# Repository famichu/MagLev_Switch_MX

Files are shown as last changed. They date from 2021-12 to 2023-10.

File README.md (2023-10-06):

# MagLev Switch MX

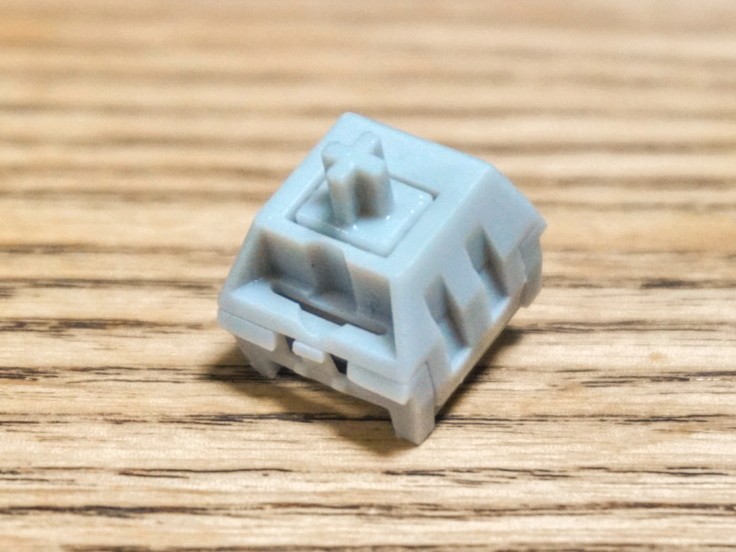
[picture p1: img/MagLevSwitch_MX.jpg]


## Summary
These 3D printable switches have linear output hall effect sensors with magnetic levitation switches. The shape of this swich is compatable with the Cherry MX switch.

## Features
- Magnetic levitation axis
- Non-contact switch
- Linear output(adjustable actuation depth)
- Able to make with only 2 magnets and a hall sensor.
- Compatible shape with Cherry MX switch

## Structure
Most MagLev switches don't use hall effect sensors. I think this is because the magnetism is too strong or the distance from the magnet is too close to for the sensor to detect. Therefore I implemented with new method that by sandwiching the hall effect sensor between two magnets instead of using springs.

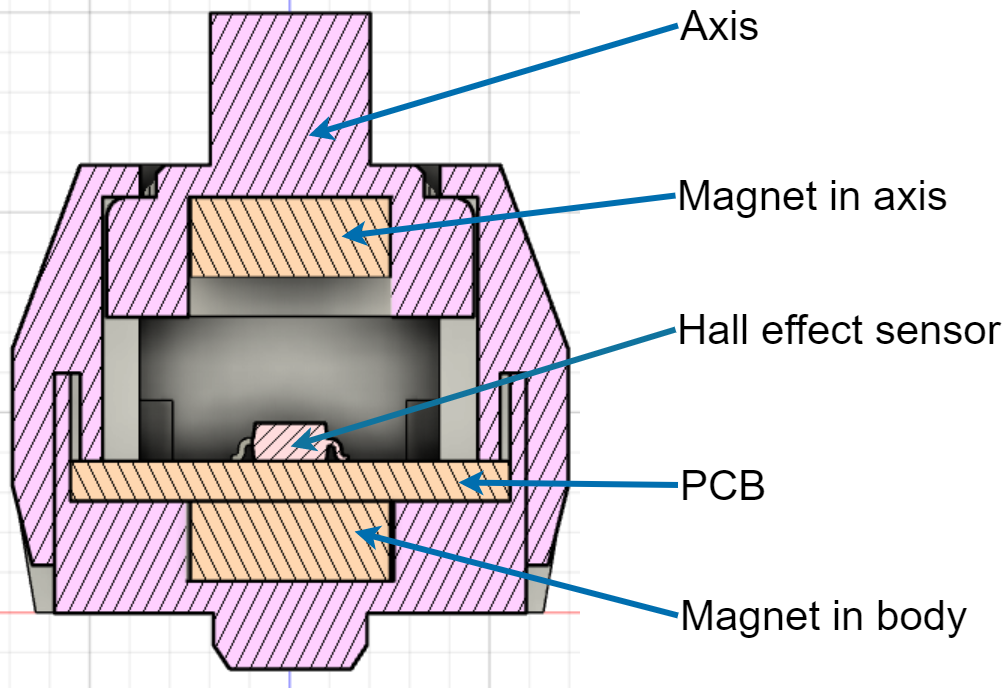
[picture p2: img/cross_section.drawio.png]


When the axis is pushed, the magnetism will cancel each other out, which causes the magnetism detected by hall effect sensor to become zero. This is how this switch works.
This method made the switch smaller, allowing it to have the same shape as existing switches.

## BOM
- PCB x1
- Hall effect sensor IC A1304 x1
- Pin header connector 1x1 x3
- 5mm diameter x 2mm height magnet x2
- Axis part(3D printerd) x1
- Botton part(3D printerd) x1
- Top part(3D printerd) x1
- Soldering jig(3D printed) x1(Optional)

### About the magnet and the hall effect sensor
The dimensions of the magnet used to make these models are 5mm diameter and 2mm thickness neodymium magnets. I used [this magnet](https://www.amazon.co.jp/gp/product/B08MJH42VK/).
The hall effect sensor I used is [A1304](https://www.allegromicro.com/~/media/Files/Datasheets/A1304-Datasheet.ashx) from Allegro MicroSystems.

## 3D Printing
I recommend to use SLA or DLP printer to print the body of the switches. And the recommended printing direction is the angle at which the groove is parallel to the platform.
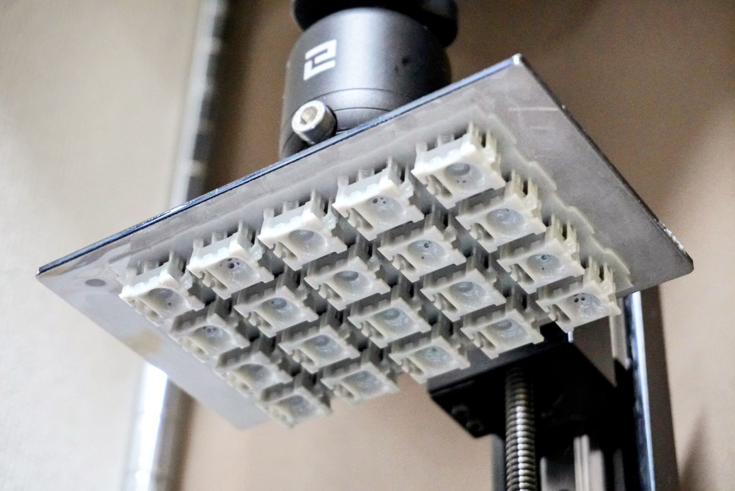
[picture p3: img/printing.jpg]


## PCB
The PCB of this switch is manufactuable with single layer. But I recommend a load-bearing double layer PCB. 
Pins I used are the usual pinheaders. They're easy install with this Soldering Jig included in the repositry.
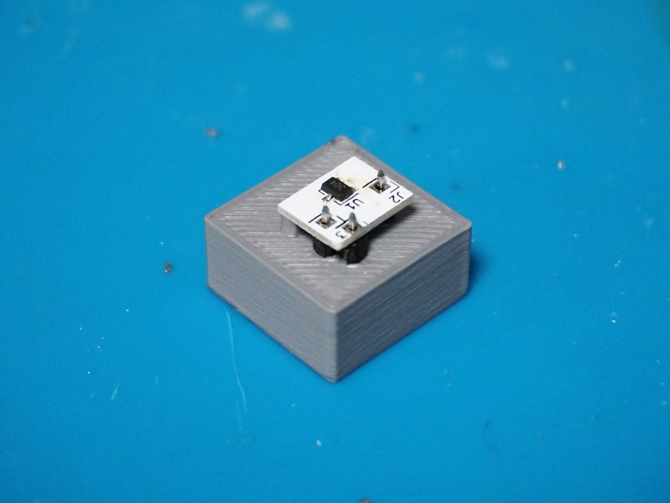
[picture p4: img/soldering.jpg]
Solodering with jig


# Sample Numeric Keypad
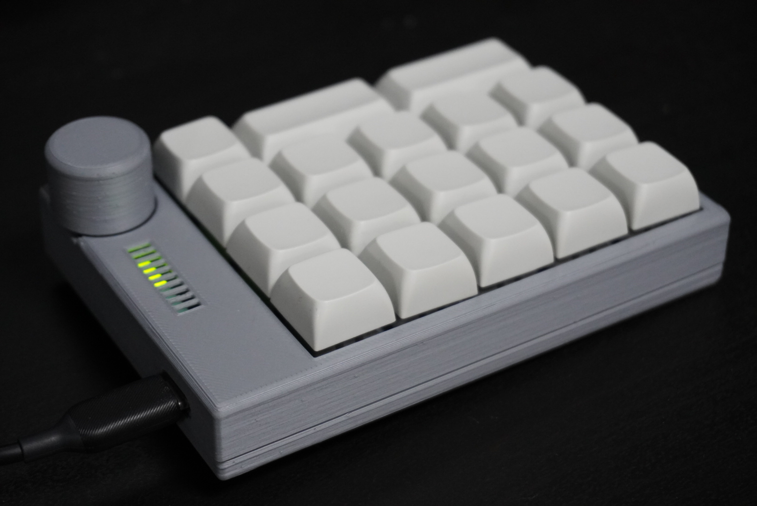
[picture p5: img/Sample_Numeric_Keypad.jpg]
Sample Numeric Keypad


## Features
- Used Maglev Switches
- Also useable with common Cherry MX switch types.
- This keypad has an LED indicator and a volume for changing the actuation depth.

## BOM
- PCB x1
- MagLev Switch MX x18
- Seeeduino Xiao x1
- Linear(B type) 10k Ohm Rotary potentiometers x1
- Broadcom LED bar graph HDSP-4850  x1
- Case bottom(3D printed) x1
- Case plate(3D printed) x1
- Case top(3D printed) x1
- Volume cap(3D printed) x1

### PCB
If you want to make the sample numeric keypad, **you'll need to download KiCAD libraries from [Seeed Wiki](https://wiki.seeedstudio.com/Seeeduino-XIAO/#resourses)**. 
Then put the "Seeeduino XIAO KICAD" directory and the "Seeeduino XIAO KICAD.pretty" directory under the "Sample_Numeric_Keypad\PCB" directory.

# Directory configuration
- **MagLevSwitch_MX**: Files for maglev switch units.
    - **Body**: 3D printable mesh files and the editable file with Fusion 360(F3Z).
    - **PCB**: KiCad project files and KiCad libraries with 3D models.
    - **SolderingJig**: 3D printable mesh files of soldering jig for the PCB of this switch.
- **Sample_Numeric_Keypad**
    - **Case**: 3D printable mesh files.
    - **Code**: Source codes for the key matrix controller(Seeeduino Xiao with ) and LED indicator(ATmega328P)
    - **PCB**: KiCad project files(**Libraries of Seeduino XIAO is not included.**).

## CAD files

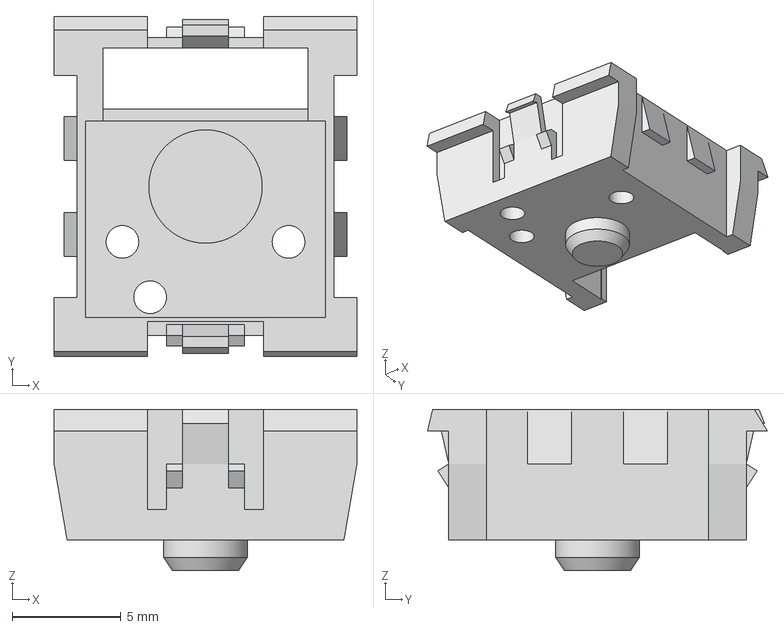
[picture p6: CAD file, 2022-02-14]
MagLevSwitch_MX/Body/BOTTOM.3mf
13.9 x 15.6 x 7.40 mm

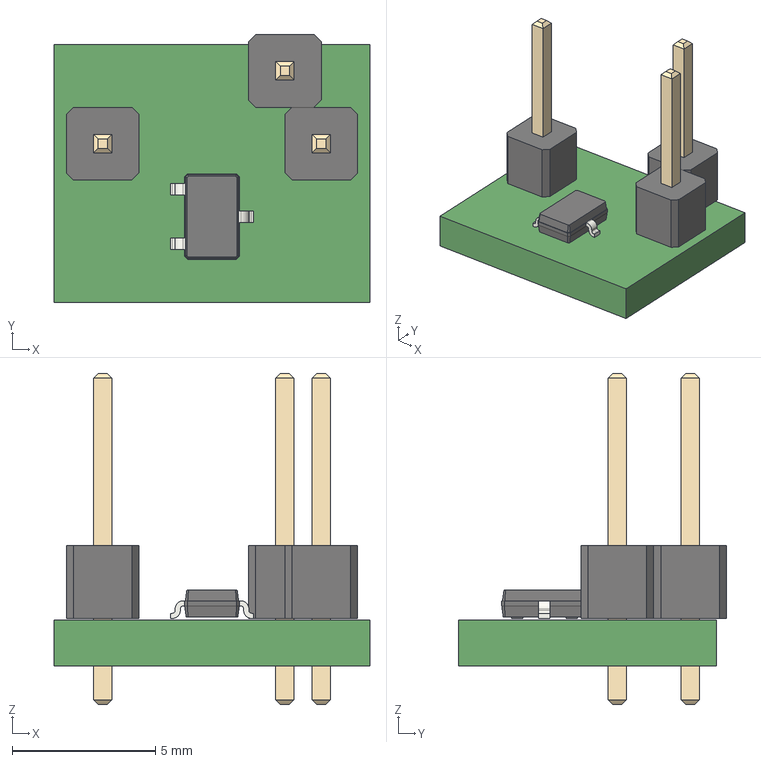
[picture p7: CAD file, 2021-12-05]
MagLevSwitch_MX/PCB/MagLev_Switch.step
11.0 x 9.35 x 11.5 mm

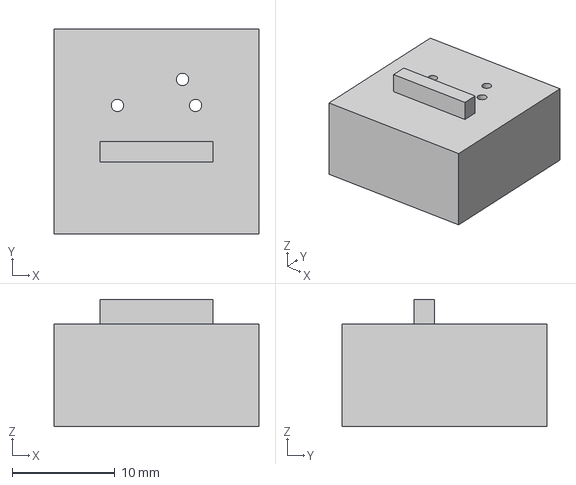
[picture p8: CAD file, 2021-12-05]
MagLevSwitch_MX/SolderingJig/SOLDERING_JIG.3mf
20.0 x 20.0 x 12.4 mm

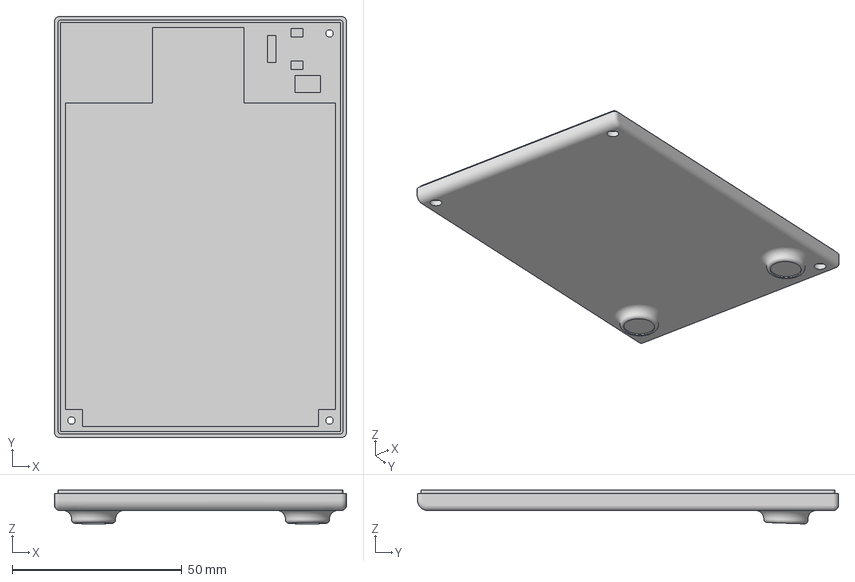
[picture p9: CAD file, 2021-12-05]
Sample_Numeric_Keypad/Case/Case_Bottom.3mf
86.0 x 124.0 x 9.96 mm

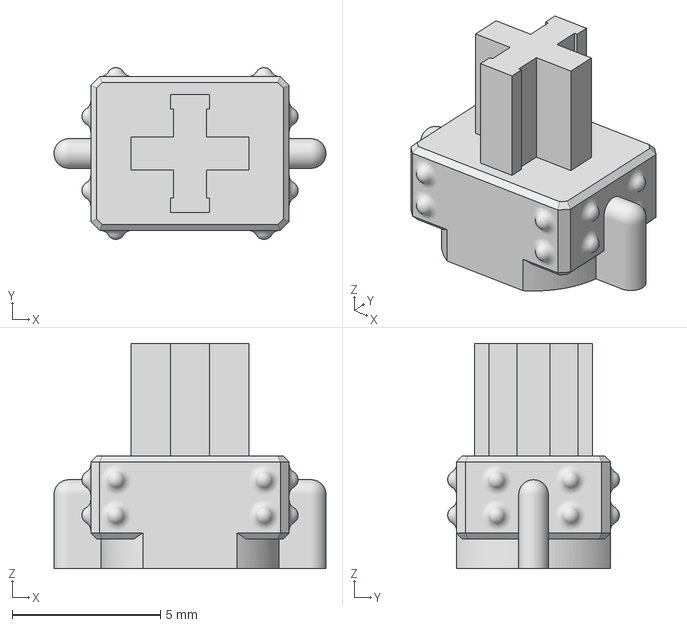
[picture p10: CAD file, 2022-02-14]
MagLevSwitch_MX/Body/AXIS.3mf
9.18 x 5.80 x 7.60 mm

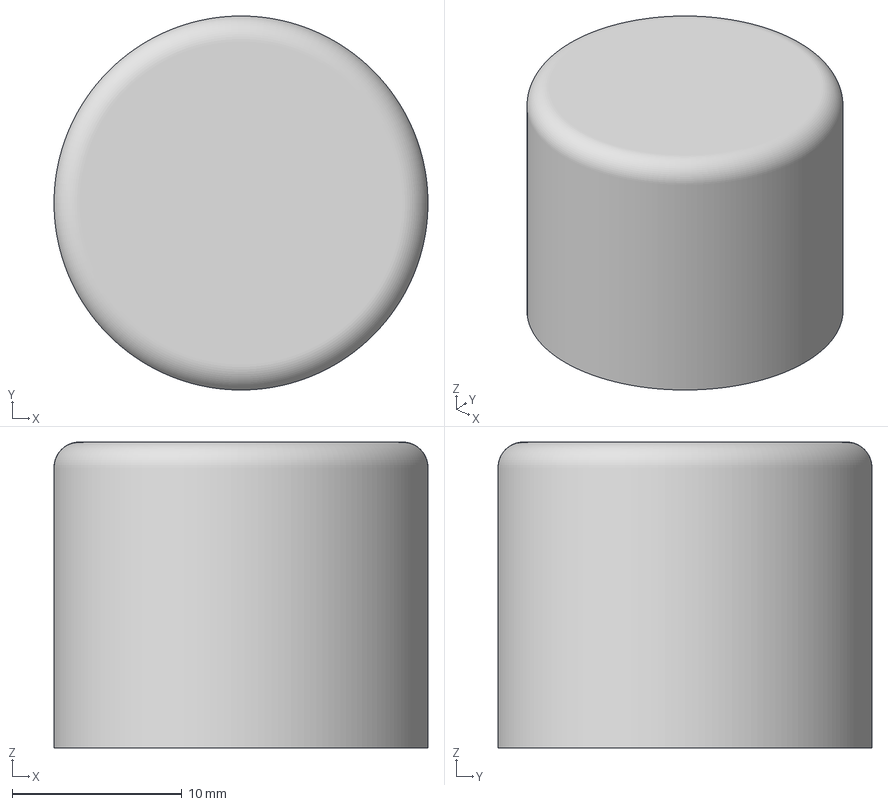
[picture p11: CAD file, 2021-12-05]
Sample_Numeric_Keypad/Case/Case_VolumeCap.3mf
22.0 x 22.0 x 18.0 mm

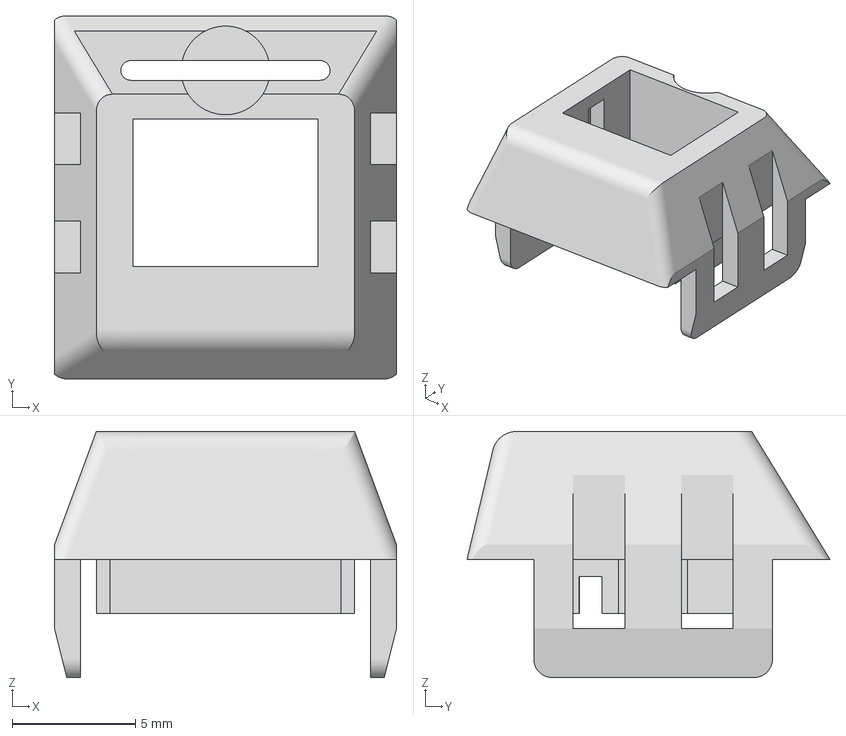
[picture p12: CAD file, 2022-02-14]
MagLevSwitch_MX/Body/TOP.3mf
13.9 x 14.8 x 10.0 mm

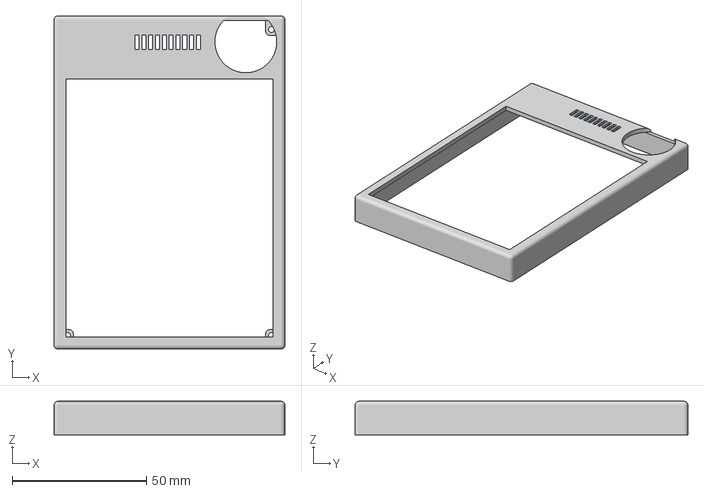
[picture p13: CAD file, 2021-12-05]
Sample_Numeric_Keypad/Case/Case_Top.3mf
86.0 x 124.0 x 12.5 mm

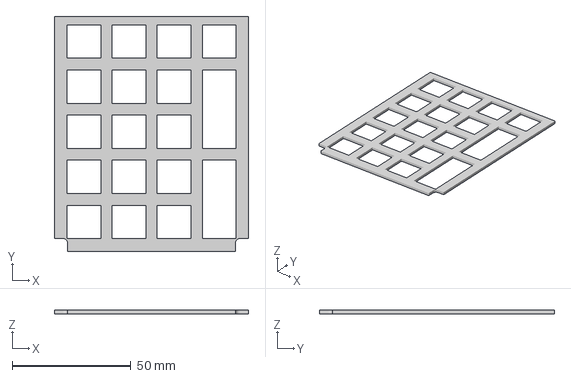
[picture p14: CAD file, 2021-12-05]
Sample_Numeric_Keypad/Case/Case_Plate.3mf
81.8 x 99.0 x 1.50 mm

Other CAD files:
MagLevSwitch_MX/Body/AXIS.stl
MagLevSwitch_MX/Body/BOTTOM.stl
MagLevSwitch_MX/Body/MagLev_Switch_MX.f3z
MagLevSwitch_MX/Body/TOP.stl
MagLevSwitch_MX/SolderingJig/SOLDERING_JIG.stl

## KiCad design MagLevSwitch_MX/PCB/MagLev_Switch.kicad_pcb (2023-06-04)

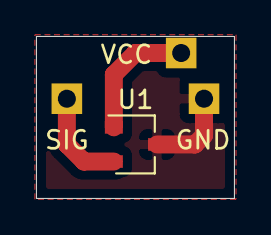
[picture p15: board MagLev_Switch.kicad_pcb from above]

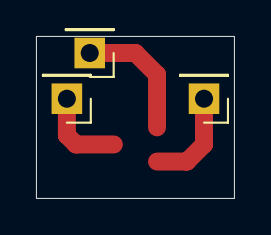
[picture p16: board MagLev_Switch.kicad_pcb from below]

Board: 2 copper layers, 11.0 x 9.0 mm, 4 parts (3 on the bottom side), 3 nets.

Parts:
GND: Conn_01x01; PinHeader_1x01_P2.54mm_Vertical
SIG: Conn_01x01; PinHeader_1x01_P2.54mm_Vertical
U1: A1302ELHLT-T; SOT-23W
VCC: Conn_01x01; PinHeader_1x01_P2.54mm_Vertical

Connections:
GND: GND.1, U1.3
unnamed: SIG.1, U1.2
VCC: U1.1, VCC.1

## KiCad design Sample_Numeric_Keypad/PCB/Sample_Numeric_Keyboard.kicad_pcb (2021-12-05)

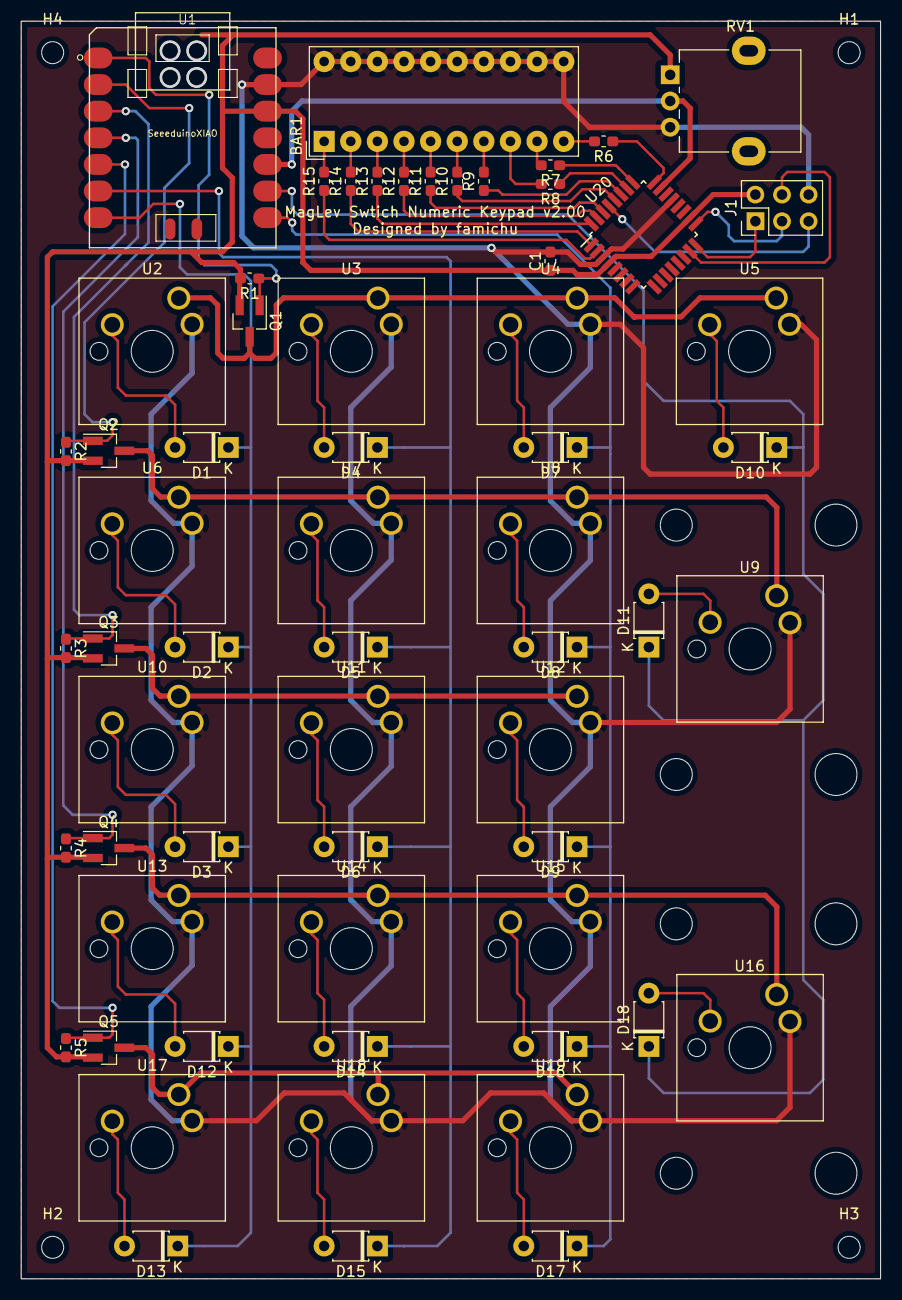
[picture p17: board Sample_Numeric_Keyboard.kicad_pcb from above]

Board: 2 copper layers, 82.0 x 120.0 mm, 66 parts (0 on the bottom side), 59 nets.

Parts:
BAR1: HDSP-4850_2; HDSP-4850
C1: C; C_0603_1608Metric_Pad1.05x0.95mm_HandSolder
D1, D2, D3, D4, D5, D6, D7, D8, D9, D10, D11, D12, D13, D14, D15, D16, D17, D18: D; D_T-1_P5.08mm_Horizontal
H1, H2, H3, H4: MountingHole; MountingHole_2.1mm
J1: Conn_02x03_Odd_Even; PinHeader_2x03_P2.54mm_Vertical
Q1, Q2, Q3, Q4, Q5: Q_PMOS_GSD; SOT-23_Handsoldering
R1, R2, R3, R4, R5: 1k; R_0603_1608Metric_Pad1.05x0.95mm_HandSolder
R6, R7, R8, R9, R10, R11, R12, R13, R14, R15: 10; R_0603_1608Metric_Pad1.05x0.95mm_HandSolder
RV1: R_POT; Potentiometer_Alpha_RD901F-40-00D_Single_Vertical
U1: SeeeduinoXIAO; Seeeduino XIAO-MOUDLE
U2, U3, U4, U5, U6, U7, U8, U10, U11, U12, U13, U14, U15, U17, U18, U19: MagLevSwitch; SW_MagLev_1.00u_PCB
U9, U16: MagLevSwitch; SW_MagLev_2.00u_Vertical_PCB
U20: ATmega328-AU; TQFP-32_7x7mm_P0.8mm

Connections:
+3V3: C1.1, J1.2, Q1.2, Q2.2, Q3.2, Q4.2, Q5.2, R1.2, R2.2, R3.2, R4.2, R5.2, RV1.1, U1.12, U20.4, U20.6, U20.18
/COL_0: D1.1, D2.1, D3.1, D12.1, D13.1, U1.7
/COL_1: D4.1, D5.1, D6.1, D14.1, D15.1, U1.6
/COL_2: D7.1, D8.1, D9.1, D16.1, D17.1, U1.8
/COL_3: D10.1, D11.1, D18.1, U1.9
/MISO: J1.1, U20.16
/MOSI: J1.4, U20.15
/ROW_0: Q1.1, R1.1, U1.1
/ROW_1: Q2.1, R2.1, U1.2
/ROW_2: Q3.1, R3.1, U1.3
/ROW_3: Q4.1, R4.1, U1.4
/ROW_4: Q5.1, R5.1, U1.5
/RST: J1.5, U20.29
/SCK: J1.3, U20.17
/VOL: RV1.2, U1.10, U20.23
GND: BAR1.11, BAR1.12, BAR1.13, BAR1.14, BAR1.15, BAR1.16, BAR1.17, BAR1.18, BAR1.19, BAR1.20, C1.2, J1.6, RV1.3, U1.13, U2.3, U3.3, U4.3, U5.3, U6.3, U7.3, U8.3, U9.3, U10.3, U11.3, U12.3, U13.3, U14.3, U15.3, U16.3, U17.3, U18.3, U19.3, U20.3, U20.5, U20.21
unnamed: BAR1.1, R15.2
unnamed: BAR1.2, R14.2
unnamed: BAR1.3, R13.2
unnamed: BAR1.4, R12.2
unnamed: BAR1.5, R11.2
unnamed: BAR1.6, R10.2
unnamed: BAR1.7, R9.2
unnamed: BAR1.8, R8.2
unnamed: BAR1.9, R7.2
unnamed: BAR1.10, R6.2
unnamed: D1.2, U2.2
unnamed: D2.2, U6.2
unnamed: D3.2, U10.2
unnamed: D4.2, U3.2
unnamed: D5.2, U7.2
unnamed: D6.2, U11.2
unnamed: D7.2, U4.2
unnamed: D8.2, U8.2
unnamed: D9.2, U12.2
unnamed: D10.2, U5.2
unnamed: D11.2, U9.2
unnamed: D12.2, U13.2
unnamed: D13.2, U17.2
unnamed: D14.2, U14.2
unnamed: D15.2, U18.2
unnamed: D16.2, U15.2
unnamed: D17.2, U19.2
unnamed: D18.2, U16.2
unnamed: Q1.3, U2.1, U3.1, U4.1, U5.1
unnamed: Q2.3, U6.1, U7.1, U8.1, U9.1
unnamed: Q3.3, U10.1, U11.1, U12.1
unnamed: Q4.3, U13.1, U14.1, U15.1, U16.1
unnamed: Q5.3, U17.1, U18.1, U19.1
unnamed: R6.1, U20.24
unnamed: R7.1, U20.25
unnamed: R8.1, U20.26
unnamed: R9.1, U20.27
unnamed: R10.1, U20.28
unnamed: R11.1, U20.30
unnamed: R12.1, U20.31
unnamed: R13.1, U20.32
unnamed: R14.1, U20.1
unnamed: R15.1, U20.2

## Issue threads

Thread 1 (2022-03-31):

Sample Numeric Keypad Components

markjhvonk, 2022-03-31:
Hi, I'm not sure if this is the right place but I'm running into some issues while trying to build the 'sample numeric keybooard'. I managed to source most of the required components however I'm still running into some issues.
After soldering all the components and uploading the script to the Seeeduino, the keypad starts outputting random letters and numbers continuously. When I tweak the  `#define ACTUATION_POINT 512` and set it to `1023` it stops continuously outputting numbers and letters but it still outputs a series of random numbers/letters when a key is pressed.
I believe it might be because I used the wrong components on some places as I had trouble figuring out which ones I need. These are the components I used (as per pcb labelling):

- Q1-5: BC847B 1F SOT-23, 45 V, 100 mA, 250 mW
- R1-15: 0603_1608 1k resistors
- D1-18: 1N4148 Diode 200 mA 100 V
- U1: SeeeduinoXIAO
- U20: ATmega328-AU
- BAR1: HDSP-4850 lighbar
- RV1: RK097N 100k ohm

famichu, 2022-03-31:
Firstly, thank you for building my keyboard. And I'm sorry about that code was not good and really complicated(even if this issue was not caused by my code).

Well, I think few causes shown as down below might cause that issue.

- break of hall IC or circuit board in the switch
- wrong direction of diodes

Anyway, I guess the random letters output from keyboard are consisted of specific characters of keys in same column.
If that, please check switches outputs on that column with multimeter(I recommend to change a program to keep supplying power to only specific row to check correctly). If output from a switch was always HIGH(even releasing a switch), that switch might be broken.

Also, if you used another hall IC, you should check the output direction or pole direction too.

Thank you😊

famichu, 2022-03-31:
@markjhvonk
Firstly, thank you for building my keyboard. And I'm sorry about that code was not good and really complicated(even if this issue was not caused by my code).

Well, I think few causes shown as down below might cause that issue.

- break of hall IC or circuit board in the switch
- wrong direction of diodes

Anyway, I guess the random letters output from keyboard are consisted of specific characters of keys in same column.
If that, please check switches outputs on that column with multimeter(I recommend to change a program to keep supplying power to only specific row to check correctly). If output from a switch was always HIGH(even releasing a switch), that switch might be broken.

Also, if you used another hall IC, you should check the output direction or pole direction too.

Thank you😊

markjhvonk, 2022-04-01:
I checked with a colleague of mine which knows a lot more about hardware/electronics than I do and he thinks I used the wrong transistors, would you happen to have an exact model number (or link) of the SOT-23 transistor you used for this pcb? I could only grab the following details from the KiCad files: `SOT-23_Handsoldering` `Q_PMOS_GSD`.
The ones I used are the `BC847B 1F` transisors which apparantly have a completely different functionality which explains the odd behaviour ;)

famichu, 2022-04-01:
@markjhvonk

Oh. I'm sorry. I didn't notice that you had used the NPN bipolar transistor... You must use Pch MOSFET(especially when use this with high frequency).
I used IRLML6402 from Infineon Technologies though, I think you can use general Pch MOSFET from other manufacturer also.
Important values are Vdss and Vgs(threshold). In this schematic, you must use the MOSFET which has lower value of Vdss than -3.3V and higher value of Vgs than -3.3V. It means, needs to suit on 3.3V power supply, and able to switch with I/O pins of 3.3V.

Just in case, the MOSFET I used is this.
https://www.digikey.com/en/products/detail/infineon-technologies/IRLML6402TRPBF/811437

I hope this comment helps you.

markjhvonk, 2022-04-01:
Ah thanks! I came to the conclusion (with my colleague) that I indeed used the wrong transistors. He suggested the DMP2100U, and he still had some laying around so I will try those this weekend.
I will let you know if this fixes the issue!
Thanks again for the help, and explanation so far!

markjhvonk, 2022-04-12:
I tried the DMP2100U transistors but they did not seem to work as espected. They also resulted in a continuous output, but this time with all the numbers in order.
I ordered the transistors which you suggested, I will let you know if this fixes the issue.

I also have another question (just to make sure) I'm using 0603 1k ohm resistors on the pcb are these the correct resistors or do I need different tolerances/resistance?

famichu, 2022-04-13:
@markjhvonk

Uh... I checked a datasheet of the DMP2100U though, that seems to work on this keyboard too.
What do you mean that "all the numbers in order."?

Those resistors are just pull-up resistors for FET gate voltage. So actually, resistance are not so important(if that's between around 1k and 100k ohm at least).

Closed 2022-07-27.

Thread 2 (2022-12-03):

What PCB thickness do i need for the switch?

chokonmainatsu, 2022-12-03:
I'm thinking about making this switch myself, but the only information i'm missing is how thick the pcb has to be, i'll probably order the pcbs at pcbway

bobson321, 2022-12-03:
1.6mm is in pcb project

famichu, 2022-12-04:
Thickness of pcbs in switches are 1.0mm.
I had forgot describe that Information. I'll add that on next commit.

Closed 2023-02-21.

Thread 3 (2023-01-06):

seeeduino problem

bobson321, 2023-01-06:
So I am about to make your sample keypad, I uploaded code to seeeduino xiao (pins are not connected to anything) and it started spamming random letters.
The only one problem in vscode is in key_board.h file on #include <ArduinoSTL.h> (Include file not found in browse.path.).
In code there was adafruit/Adafruit TinyUSB Library@1.14.4 which is not working for me so I used 1.10.0 version instead
I don't know if it is supposed to work like this.

Closed 2023-01-09.

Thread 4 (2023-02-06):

two problems to keypad completion

bobson321, 2023-02-06:
Hi, I am in the process of making your keypad and I have two problems one is 3d printing, we used resin and the printouts are bad(they are falling apart and have wrong dimensions), the second problem is programming atmega bcs I have no clue how to do it. The keypad is almost completed and only these two thing are needed to complete
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

famichu, 2023-02-06:
Hi, bobson321. Thank you for building my switches and a keyboard.

Firstly, an accuracy of 3D printing are depends on various things. I can't explain all things on here though, you must to do 3 points below at least.

- Find proper settings for that resin on that 3D printer(settings also depends on temperature).
- Append supports as many as you can on edges of the model when you slice(This makes easy to print small parts too).
- Dry printed parts well before secondary hardening(This process makes that parts dimensions more correctly).

And a transparent resin is especially difficult to print as correct dimensions. I recommend to use an opaque resin.

Then, to write code to the atmega, you need to use a writer like a USBasp(or you can make this with arduino).
If you use USBasp, [this thread](https://www.instructables.com/Programming-Microcontrollers-With-a-USBasp-Program/) will be helpful.
My code which works on the atmega are made with the Microchip Studio. So you need to Install that first.

bobson321, 2023-02-06:
Thank you for replying. I have another question what material did you use if resin what type

famichu, 2023-02-07:
I was using [ELEGOO Water Washable Rapid Resin](https://www.elegoo.com/en-jp/products/elegoo-water-washable-resin).
 But in general, usual resin(non water washable resin) is easier to print detail.

bobson321, 2023-02-19:
Do you have technical drawing with dimensions? That would be helpful

famichu, 2023-02-21:
Are you talking about tolerance? I didn't mentioned about that, I was using axises only that has error of size less than 0.5% for width and depth.
If you need to know dimensions(width, depth, height, for each parts'), please open f3z files and measure those in Fusion360.

Closed 2023-03-31.

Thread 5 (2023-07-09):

Would millisecond timer make it work?

ThunderrGodd, 2023-07-09:
Hi, I'm interested in your MagLev switch concept and planning for 60% or 65% keyboard using it.
My plan is RP2040 built-in PCB, but I'm worrying about timer.
Your code is based on microsecond timer, and as I see, default interval is just 1000us(1ms).
As I searched, RP2040 timer is based on milliseconds, so I can't be sure it will work.
How do you think about it? Do you think porting it to RP2040 is possible?
I'm still a beginner at programming, need your advice.

famichu, 2023-07-09:
Thank you for trying to build my switch.
I think it's possible. But if you build another size of keyborads, I recommend to create program from scratch. This switch is techniculy just normal linear input devices like a potentiometer. That means it's possible to use with milliseconds timer too(That depends on specification of controllers though).

Closed 2023-07-09.

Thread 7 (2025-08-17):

[Idea] ElectroMagLev Keyboard Switch: use tiny electromagnet for adjustable resistance and rebound

FluorescentHallucinogen, 2025-08-17:
What about replacing one of the permanent magnets (obviously in the body of the switch, not axis) with a tiny electromagnet?

The strength of the electromagnet could be controlled by current. It could even be variable and depend on the Hall effect sensor readings.

I would call it _ElectroMagLev_, short for _ElectroMagnetic Levitation_.

Imagine being able to fully customize the haptic feedback, adjust not just the actuation point, but also the resistance and rebound speed of each key using a user-friendly graphical interface e.g. via mouse (Force-Travel Curve Editor). See image.

This level of customization allows users to emulate the behavior of almost any keyboard switches available on the market or create a truly personalized typing experience, tailored to their specific needs and preferences.

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

famichu, 2025-08-21:
Hi! Thank you for your suggestion.
I've actually made something very similar to your idea in my new project, which I've named the "MagLev Switch Force Feedback".
video: https://x.com/famichu/status/1901167763214798891

However, so far I've only implemented a function that changes the electromagnet's strength to a specific value using buttons (meaning the strength of the electromagnet is fixed throughout the entire keystroke). This means a programmable "key feel" isn't available yet.
I think a GUI like the one you suggested would be a great way to implement that new feature.

One potential problem is the actuation depth.
My switch senses depth by measuring the decrease in magnetic flux density. Therefore, if the strength of the electromagnet changes, the baseline for sensing depth also shifts.(You can also see this phenomenon in the video I shared earlier.)
Though I think it might be possible to calibrate for this in the firmware, perhaps by using a lookup table or a correction formula.

FluorescentHallucinogen, 2025-08-21:
Thank you so much for sharing the video! Your prototype is living proof that the idea is viable!

I understand that this is just a prototype, but I see you've used a pretty big electromagnet. Isn't that overkill? What force does it create? What is its energy consumption?

I see you even had to use a radiator. How hot does it get?

The main question is whether it is technically possible to replicate this using a tiny electromagnet in the form-factor of Cherry MX switch or similar?

Would using a solenoid be more effective?

> if the strength of the electromagnet changes, the baseline for sensing depth also shifts

That was, by the way, the first thing I thought of. :)

Besides the correction formula or precomputed table, a potentially simpler-to-implement option that comes to mind is replacing the Hall effect sensor with an optical sensor. Something like:

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

As for the GUI (Force-Travel Curve Editor), I would be happy to help with it. :wink:

Closed 2025-09-20.

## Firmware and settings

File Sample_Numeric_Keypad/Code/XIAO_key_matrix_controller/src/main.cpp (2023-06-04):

#include <Arduino.h>
#include <TimerTC3.h>
#include <TinyUSB_Mouse_and_Keyboard.h>

#include <key_switch.cpp>
#include <fet.cpp>

// Pins for row of the matrix
#define PIN_ROW_0 0
#define PIN_ROW_1 1
#define PIN_ROW_2 2
#define PIN_ROW_3 3
#define PIN_ROW_4 4

// Pins for col of the matrix
#define PIN_COL_0 A6
#define PIN_COL_1 A5
#define PIN_COL_2 A7
#define PIN_COL_3 A8

// A pin for actuation depth volume
#define PIN_VOL A9

const u_int16_t PULSE_FREQ = 50;     // Frequency for scanning the state of swiches
const u_int16_t LOWER_LIMIT = 300;   // Lower limit of the actuation depth
const u_int16_t UPPER_LIMIT = 900;   // Upper limit of the actuation depth

const u_int8_t G_ROW_PINS[]   = {PIN_ROW_0, PIN_ROW_1, PIN_ROW_2, PIN_ROW_3, PIN_ROW_4};    // Pins connected to FETs
const u_int8_t G_COL_PINS[]   = {PIN_COL_0, PIN_COL_1, PIN_COL_2, PIN_COL_3};               // Pins connected to Key switches

// Keycode map for each key
char G_KEY_CODES[5][4] = {
    {0xB2, '/', '*', '-'}, 
    {'7', '8', '9', 0x6B}, 
    {'4', '5', '6', ' '}, 
    {'1', '2', '3', 0xB0}, 
    {'0', '0', '.', ' '}
};

KeySwitch G_KEY_SWITCHES[sizeof(G_ROW_PINS)][sizeof(G_COL_PINS)]; // KeySwitch Object
FET G_FETS[sizeof(G_ROW_PINS)]; // FET Object

int actuation_depth; // Global variable to put actuation depth.

// Prototypes
int updateActuationDepth();
void updateState();


void setup() {
    // Get initial actuation depth and begin Keyboard.
    actuation_depth = updateActuationDepth();
    Keyboard.begin();

    // Make instances of key switches.
    for(u_int8_t row = 0; row < sizeof(G_ROW_PINS); row++){
        G_FETS[row] = FET(G_ROW_PINS[row], true);
        for(u_int8_t col = 0; col < sizeof(G_COL_PINS); col++){
            G_KEY_SWITCHES[row][col] = KeySwitch(G_COL_PINS[col], G_KEY_CODES[row][col], false, true, &actuation_depth);
        }
    }

    // Set timer interrupt
    TimerTc3.initialize(1000000 / (PULSE_FREQ * sizeof(G_ROW_PINS) * 4));
    TimerTc3.attachInterrupt(updateState);
}

void loop() {
    // Nothing to do in loop method.
    // Codes are working only by timer interrupt.
}


// Update actuation depth set with volume.
int updateActuationDepth(){
    int result = max(LOWER_LIMIT, analogRead(PIN_VOL));
    result = min(result, UPPER_LIMIT);

    return result;    
}


// Update switches status. This method are called only by timer interrupt.
void updateState(){
    static size_t row = 0;
    static u_int8_t off_count = 0;
    actuation_depth = updateActuationDepth();

    if(row >= sizeof(G_ROW_PINS)){
        row = 0;
    }
    if(G_FETS[row].is_on()){
        for(size_t col = 0; col < sizeof(G_COL_PINS); col++){
            G_KEY_SWITCHES[row][col].UpdateState();

            if((row == 4) && (col == 1)){
                if(G_KEY_SWITCHES[row][col].IsPushed() && !G_KEY_SWITCHES[row][col].IsLongPushed()){
                    Keyboard.print("00");
                }
            }
            else if((row == 0) && (col == 2)){
                if(G_KEY_SWITCHES[row][col].IsPushed()){
                    Keyboard.press(0x85);
                    Keyboard.press('8');
                }
                else if(G_KEY_SWITCHES[row][col].IsReleased()){
                    Keyboard.release(0x85);
                    Keyboard.release('8');
                }
            }
            else if((row == 1) && (col == 3)){
                if(G_KEY_SWITCHES[row][col].IsPushed()){
                    Keyboard.press(0x85);
                    Keyboard.press('=');
                }
                else if(G_KEY_SWITCHES[row][col].IsReleased()){
                    Keyboard.release(0x85);
                    Keyboard.release('=');
                }
            }
            else{
                if(G_KEY_SWITCHES[row][col].IsPushed()){
                    Keyboard.press(G_KEY_SWITCHES[row][col].Keycode());
                }
                else if(G_KEY_SWITCHES[row][col].IsReleased()){
                    Keyboard.release(G_KEY_SWITCHES[row][col].Keycode());
                }
            }
        }
        G_FETS[row].output(false);
        row++;
    }
    else{
        off_count++;
        if(off_count >= 3){
            off_count =  0;
            G_FETS[row].output(true);
        }
    }
}

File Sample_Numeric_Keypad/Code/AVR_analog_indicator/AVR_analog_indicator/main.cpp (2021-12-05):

/*
 * AVR_analog_indicator.cpp
 *
 * Created: 2021/10/01 23:15:00
 * Author : famichu
 */

#include <avr/io.h>

#define LED01 0b00000010
#define LED02 0b00000100
#define LED03 0b00001000
#define LED04 0b00010000
#define LED05 0b00100000
#define LED06 0b00000001
#define LED07 0b00000010
#define LED08 0b00000100
#define LED09 0b00001000
#define LED10 0b00010000


int main(void)
{
	DDRC	= 0b00111110;
	DDRD	= 0b00011111;
	PORTC	= 0b00000000;;
	
	ADMUX	|= (1 << REFS0);
	ADCSRA	|= (1 << ADEN) | (1 << ADATE) | (0 << ADPS2) | (0 << ADPS1) | (0 << ADPS0);
	ADCSRB	&= 0b11010000;
	ADCSRA	|= (1 << ADSC);
	
	unsigned int val;
	
    while (1) 
    {
		if(ADCSRA & (1 << ADIF)){
			val = ADC;
			
			if(val >= 1000){
				PORTD = PORTD | LED10;
			}
			else{
				PORTD = PORTD & LED10;
			}
			if(val >= 900){
				PORTD = PORTD | LED09;
			}
			else{
				PORTD = PORTD & LED09;
			}
			if(val >= 800){
				PORTD = PORTD | LED08;
			}
			else{
				PORTD = PORTD & LED08;
			}
			if(val >= 700){
				PORTD = PORTD | LED07;
			}
			else{
				PORTD = PORTD & LED07;
			}
			if(val >= 600){
				PORTD = PORTD | LED06;
			}
			else{
				PORTD = PORTD & LED06;
			}
			if(val >= 500){
				PORTC = PORTC | LED05;
			}
			else{
				PORTC = PORTC & LED05;
			}
			if(val >= 400){
				PORTC = PORTC | LED04;
			}
			else{
				PORTC = PORTC & LED04;
			}
			if(val >= 300){
				PORTC = PORTC | LED03;
			}
			else{
				PORTC = PORTC & LED03;
			}
			if(val >= 200){
				PORTC = PORTC | LED02;
			}
			else{
				PORTC = PORTC & LED02;
			}
			if(val >= 100){
				PORTC = PORTC | LED01;
			}
			else{
				PORTC = PORTC & LED01;
			}
		}
    }
}

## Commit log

2021-12-05 publish the maglev switch and sample numeric keypad
    [AXIS.3mf, AXIS.stl, BOTTOM.3mf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]
2022-02-01 Add "Features", "BOM", "Structure" items.
2022-02-14 Update the axis shape
    Changing the axis shape to reduce the frictional resistance between axis and body.
    [AXIS.3mf, AXIS.stl, BOTTOM.3mf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]
2023-06-04 Fix code, change LICENSE and silk of PCB
    [MagLev_Switch.kicad_pcb]
2023-10-06 Update README.md
    英語訳をもうちょっと自然な方にしますた！
    多分これで英語を読む方でももう少し読みやすくなると思います！
    Changed English translation to a more natural one. It should prolly make it more easy to read than b4. GG!
